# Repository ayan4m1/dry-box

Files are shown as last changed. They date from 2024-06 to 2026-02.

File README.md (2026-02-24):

# My Filament Dry Box Adventure

I'm not the first person to do this, but I wanted to document my specific method in case others find it useful.

I wanted a setup that could keep at least 20 spools of filament in a low-humidity (5-15%) environment.

The Sterilite 20 quart gasket box was chosen because it is popular for this purpose and fits my basic needs - it fits four 1kg spools of filament with minimal wasted space and the lid is gasketed to help keep moisture out.

I found a [spool holder design](https://www.printables.com/model/139303-sterilite-20-qt-gasket-box-spool-rack) on Printables by RCNet that uses 3/8" aluminum tubing, which can be bought in a coil and straightened, then cut to length and mounted between the endcaps to let four typical-size 1kg filament spools rest vertically in the box.

3A Molecular Sieve was chosen as the dessicant because it removes more water, faster than silica gel. It does take more heat/time to dry it back out than silica gel, but this should not be an issue if you have enough molecular sieve to rotate it.

I also wanted warnings/alarms for when the sieve granules needed changing, so the LOLIN D1 Mini was chosen as the microcontroller. They are cheap ($3.70 as of this writing), small, and fairly well designed.

**Energy Use Tangent:** The current draw of each ESP8266 in this application is estimated at 70mA based on [this research](https://www.ondrovo.com/a/20170207-esp-consumption/). That's 67mA continuously with "periodic spikes" which add up to an average of 3mA. This means that every six boxes consumes 420mA, or 50 Wh of energy a day (about $0.14/mo at my electricity prices) - assuming I make no optimizations whatsoever for the device to sleep in between polling periods. My television consumes ~260 Wh in standby mode every day. I could likely drop the average current for six sensors to 100mA with sleep optimizations. They would then consume 22 times less power than my television.

There is an SHT30 shield for the D1 mini, which provides our humidity sensing and is simple to socket onto the D1 mini. The SHT30 is a fairly accurate sensor (±2% RH) which will suffice for these purposes.

The firmware uses [ESP_WiFiManager_Lite](https://github.com/khoih-prog/ESP_WiFiManager_Lite) to simplify setup and configuration of the sensors. On first flashing, the sensor will go into Access Point mode with an SSID of `dry_box_1` and the password `drybox123`. Connect to it, then navigate to `http://192.168.4.1` in your browser. Set the WiFi credentials, device name, polling rate, humidity thresholds, and Discord webhook, then click Save. The device will reboot and start functioning. If you need to change configuration, "double-tap" the reset button on the microcontroller and wait a few seconds for a solid blue LED. This means that it is in Access Point mode again.

## Bill of Materials

### [LOLIN D1 Mini V4](https://www.aliexpress.us/item/3256806460241404.html)

The link above is the official LOLIN Aliexpress store. If it becomes unavailable, you can find clones of it by searching ["d1 mini v4"](https://www.amazon.com/ACEIRMC-Internet-ESP8266-Compatible-MicroPython/dp/B0CFY382JX) on Amazon.

### [LOLIN SHT30 Shield](https://www.aliexpress.us/item/2251832575822188.html)

The link above is the official LOLIN Aliexpress store. If this link becomes unavailable, you can use any [SHT30 Breakout Board](https://www.dfrobot.com/product-2012.html) and wire it to a [JST-SH1.0 4P connector](https://www.adafruit.com/product/4209). There is a receptacle labeled I2C on the bottom right of the D1 Mini v4 which accepts this connector.

### [USB-A to USB-C Cable](https://www.amazon.com/tekSonic-10-Pack-Type-C-Cables-Charge/dp/B0CG4GM7PM)

You need one of these for each dry box, to power the sensor inside. You will be chopping the USB-C ends off of these, in order to get the wire through the hole in the box.

The cables I got had fabric weave wrapping - this meant extra complexity because I had to trim the fraying ends and use CA glue to fix them in place 1-2 inches before the end of the USB cable. This gives enough room for stripping the wires later on.

### [USB-C Connector Breakout](https://www.amazon.com/ANMBEST-Connector-Receptacle-Adapter-Support/dp/B091CRLJM2)

In case the Amazon link above stops working, this is what you're looking for:

usb connector breakout close-up

### [M2 Threaded Inserts](https://www.amazon.com/AIEX-Printing-Embedment-Automotive-M2x3x3-5mm/dp/B0B8GN63S2)

These are for the sensor holders.

### [Sterilite 20 qt Boxes](https://www.amazon.com/Sterilite-19344304-Latched-Plastic-Container/dp/B002BA5F3O)

Amazon currently offers 6, 12, 18, and 24 packs. If this listing becomes unavailable, try [Target](https://www.target.com/p/sterilite-20-qt-gasket-box-stackable-storage-bin-with-latching-lid-and-tight-seal-plastic-container-to-organize-basement-clear-base-and-lid-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), [Walmart](https://www.walmart.com/ip/Sterilite-20-Quart-Clear-Plastic-Stacking-Storage-Container-with-Gasket-Lid-6-Pack/633637534), or [Home Depot](https://www.homedepot.com/p/Sterilite-20-Qt-Gasket-Box-with-Clear-Base-and-Lid-6-Pack-6-x-19324306/312922371).

### [3/8" Aluminum Tubing](https://www.amazon.com/Tubing-Aluminium-Refrigeration-Equipment-air-conditioning/dp/B0C43X6JR4)

This will be cut to 325 mm (12.75 inch) sections to act as the spool holders.

### [3A Molecular Sieve](https://www.amazon.com/Wisesorb-Molecular-Desiccant-Dehumidifier-Absorbers/dp/B085W6TXJ8)

The 2 pound size would provide for ~150 grams of sieve per box, in a six box setup.

graph showing molecular sieve taking about 15 minutes to dry to 15 percent RH

## Price Estimate

This is an estimate for a six box, 24-spool setup based on prices I paid in June 2024.

| Parts | Net Cost |
| --- | --- |
| D1 Mini | $23 |
| SHT30 Shield | $18 |
| USB Cable | $12 |
| Molecular Sieve  | $18 |
| 20 qt Boxes | $54 |
| USB Cables | $6 |
| USB-C Breakouts  | $5 |
| Threaded Inserts | $8 |
| Aluminum Tube | $25 |
| Total | $169 |

## Tools

- Drill
- CA glue
- Glue Gun
- Soldering Iron
- Wire Strippers (12-24 AWG)
- Belt Sander (or sandpaper and patience)
- [M2 Threaded Insert Tip for Soldering Iron](https://www.amazon.com/Virtjoule-Heat-Insert-Tips-Sizes/dp/B08B17VQLD)
- [3/8" Tubing Straightener](https://www.amazon.com/Watris-Veiyi-Straightener-Universal-Straightening/dp/B0BLYYPN91)
- [Metal Tubing Cutter](https://www.amazon.com/RIDGID-32975-Quarters-Tubing-Cutter/dp/B000LDGNCU)

## 3D Printed Parts

- Endcaps for aluminum tubing
- Dessicant tray
- Sensor mount

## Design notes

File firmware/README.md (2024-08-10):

# dry-box firmware

## parts

- [LOLIN D1 Mini](https://www.aliexpress.us/item/2251832342786284.html)
- [LOLIN SHT30 Shield for D1 Mini](https://www.aliexpress.us/item/2251832575822188.html)
- **todo:** add STL files for 3D print mount model

## usage

1. Open this directory in VS Code with PlatformIO installed.
2. Connect the target device via USB.
3. Use the `PlatformIO > Upload` action to flash the firmware.
4. Connect to the WiFi AP `Dry Box 1` with PSK `drybox123`.
5. Your browser should open and take you to the config page automatically. If not, go to `http://192.168.4.1`.
6. Set your WiFi settings, Discord Webhook URL, humidity thresholds, and polling rate. Click Save.
7. The device will now reboot and should be operational.

**NOTE:** Double-tap the reset button and wait a few seconds for a solid blue LED to get back into the config AP interface later on.

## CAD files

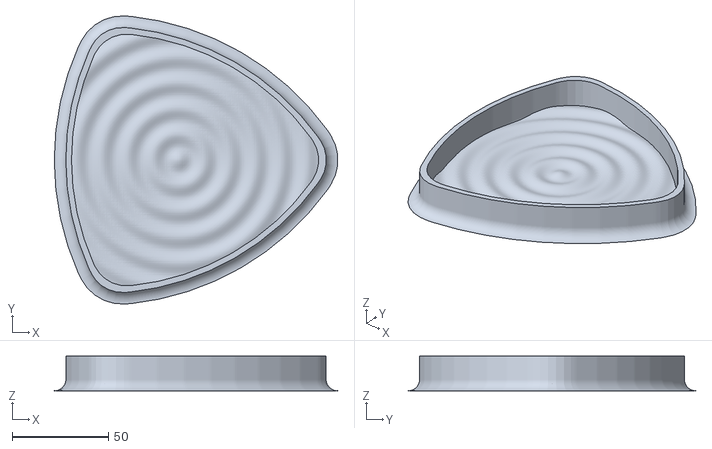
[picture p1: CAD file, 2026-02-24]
mechanical/dry-box-dessicant-tray.stl
147.0 x 149.4 x 18.0

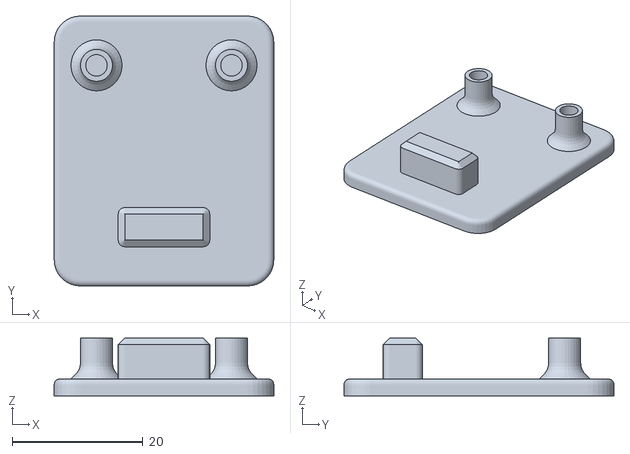
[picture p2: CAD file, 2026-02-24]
mechanical/dry-box-sensor-mount.stl
33.6 x 41.3 x 8.85

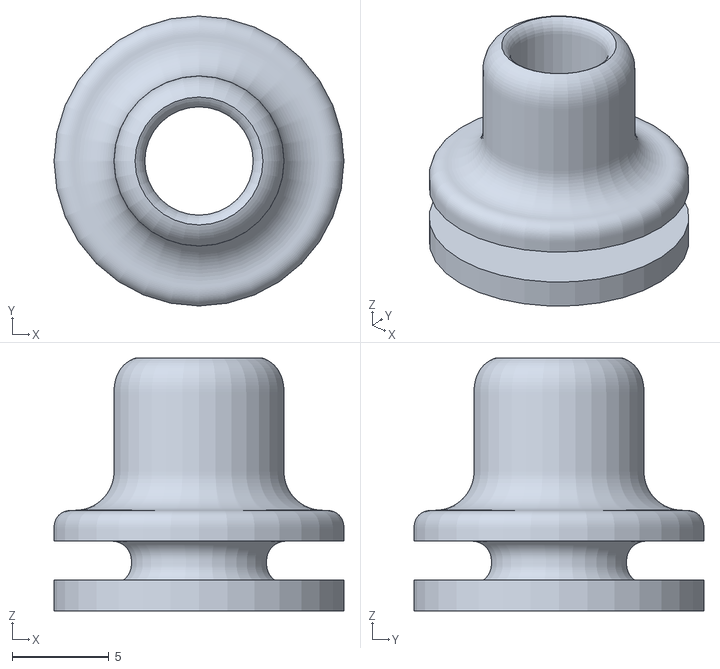
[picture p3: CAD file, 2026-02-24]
mechanical/dry-box-cable-gasket.stl
15.0 x 15.0 x 13.1

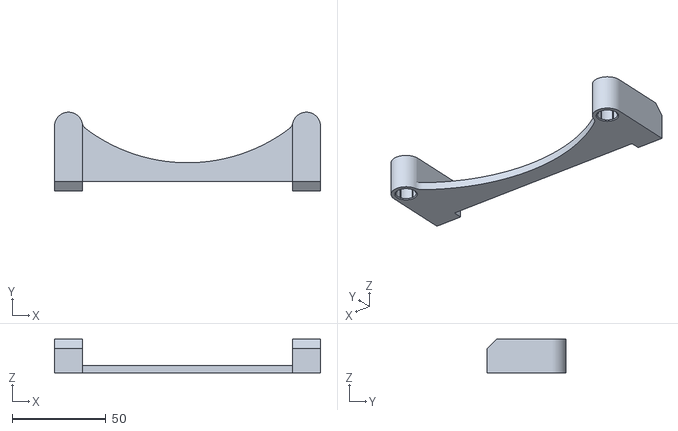
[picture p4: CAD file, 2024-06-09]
mechanical/spool-rack-endcap.stl
142.0 x 42.0 x 18.0

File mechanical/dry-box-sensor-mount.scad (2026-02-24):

include <BOSL2/std.scad>
include <BOSL2/rounding.scad>

$fn = 32;

d1_mini_dims = [25.6, 33.3, 1.6];

case_fillet = 2;
case_padding = 4;
case_rounding = 4;
case_height = 2.6;
case_inner_dims = [d1_mini_dims[0] + (case_padding * 2), d1_mini_dims[1] + (case_padding * 2)];

hole_diameter = 3 + 0.3;
hole_offset = 20.65;
hole_offsets = [[(d1_mini_dims[0] - hole_offset) / 2, 29.75], [(d1_mini_dims[0] + hole_offset) / 2, 29.75]];
insert_height = 3.5 * 1.5;

standoff_padding = 0.8;
standoff_height = insert_height + 1;
standoff_diameter = hole_diameter + (standoff_padding * 2);

prop_dims = [14, 6, standoff_height];
prop_offset = [0, -(d1_mini_dims[1] - 10) / 2, 0];

module case() {
union() {
translate([0, 0, case_height / 2]) offset_sweep(rect(case_inner_dims, rounding = case_rounding), top=os_smooth(joint = case_fillet / 2), height = case_height, steps=$fn);
translate([prop_offset[0], prop_offset[1], case_height + prop_dims[2] / 2]) offset_sweep(rect([prop_dims[0], prop_dims[1]], rounding = 1), top=os_chamfer(width = 1), height = prop_dims[2], steps = $fn);
}
}

module standoff() {
union() {
difference() {
    cylinder(d = standoff_diameter, h = standoff_height);
    translate([0, 0, standoff_height - insert_height]) cylinder(d = hole_diameter, h = insert_height);
}
rotate_extrude() translate([standoff_diameter / 2, 0, 0]) mask2d_teardrop(d = standoff_diameter);
}
}

/*%color("blue") render() translate([d1_mini_dims[0] / 2, -d1_mini_dims[1] / 2, 10]) rotate([180, 0, 180]) difference() {
    cube(d1_mini_dims);
    for(i = [0 : len(hole_offsets) - 1]) {
        hole_offset = hole_offsets[i];
        translate([hole_offset[0], hole_offset[1], 0]) cylinder(d = hole_diameter, h = d1_mini_dims[2]); 
    }
}*/

union() {
case();

translate([-d1_mini_dims[0] / 2, -d1_mini_dims[1] / 2, case_height]) {
    for(i = [0 : len(hole_offsets) - 1]) {
        hole_offset = hole_offsets[i];
        translate([hole_offset[0], hole_offset[1], 0]) standoff();
    }
}
}

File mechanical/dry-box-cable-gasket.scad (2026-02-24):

include <BOSL2/std.scad>
include <BOSL2/rounding.scad>

hole_diameter = 7;
cable_diameter = 5.6;
gasket_diameter_padding = 4;
gasket_diameter = hole_diameter + (gasket_diameter_padding * 2);
box_wall_thickness = 2;
gasket_wall_thickness = 1.6;
strain_relief_wall_thickness = 1.6;
strain_relief_height = 8;
strain_relief_diameter = cable_diameter + (strain_relief_wall_thickness * 2);

gasket_bottom_height = box_wall_thickness + (gasket_wall_thickness * 2);
gasket_height = gasket_bottom_height + strain_relief_height;

$fn = 32;

module ring(d_outer, d_inner, height) {
    difference() {
        cylinder(d = d_outer, h = height);
        translate([0, 0, (height / 2) - 0.1]) offset_sweep(circle(d = d_inner), height = height + 0.2, top = os_circle(r = -height / 2), bottom = os_circle(r = -height / 2));
    }
}

difference() {
union() {
translate([0, 0, gasket_bottom_height / 2]) offset_sweep(circle(d = gasket_diameter), height = gasket_bottom_height, top = os_smooth(joint = 1));
translate([0, 0, gasket_bottom_height + (strain_relief_height / 2)]) offset_sweep(circle(d = strain_relief_diameter), height = strain_relief_height, top = os_smooth(joint = 2), bottom = os_circle(r = -gasket_diameter_padding / 2));
}

translate([0, 0, gasket_height]) rounding_hole_mask(d = cable_diameter, rounding = 1);

translate([0, 0, (gasket_bottom_height - box_wall_thickness) / 2]) ring(gasket_diameter + 0.1, hole_diameter, box_wall_thickness);

translate([0, 0, -0.1]) cylinder(d = cable_diameter, h = gasket_height + 0.2);
}

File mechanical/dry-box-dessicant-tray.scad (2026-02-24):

include <BOSL2/std.scad>
include <BOSL2/rounding.scad>

$fn = 32;

tray_radius = 80;
tray_height = 18;
tray_rounding = 18;
tray_flare = -6;
tray_inner_fillet = 2;
tray_wall_thickness = 2;

anchor_points = [
    LEFT,
    TOP,
    DOWN,
    RIGHT+DOWN,
    LEFT+DOWN,
    LEFT+UP,
    RIGHT+UP,
    "tip0"
];

cutout_radius = 4;
cutout_thickness = tray_wall_thickness * 4;
cutout_magic_offset = [0, -4.5, 4];

module tray_shell(radius) {
    reuleaux_polygon(n = 3, r = radius);
}
function tray_shell(radius) =
    reuleaux_polygon(n = 3, r = radius);
function round_tray_shell(radius) =
    round_corners(tray_shell(radius), radius = tray_rounding);
module swept_round_tray_shell(radius = tray_radius, flare = undef) {
    offset_sweep(round_tray_shell(radius), height = tray_height, bottom = flare, steps=$fn);
}

ripple_height = 0.8;
ripple_density = 12;
ripple_function = function (x,y) ripple_height * cos(ripple_density * norm([x,y]));

module ripple() {
translate([0, 0, ripple_height]) intersection() {
    heightfield(size=[tray_radius * 2, tray_radius * 2], bottom=-2, data=ripple_function, xrange=[-180:2:180], yrange=[-180:2:180]);
    translate([0, 0, -tray_height / 2]) linear_extrude(tray_height) tray_shell(tray_radius - (tray_wall_thickness * 2) + tray_wall_thickness / 2);
}
}

difference() {
    swept_round_tray_shell(flare = os_circle(r = tray_flare));
    translate([0, 0, tray_wall_thickness]) swept_round_tray_shell(radius = tray_radius - tray_wall_thickness * 2, flare = os_smooth(joint = tray_inner_fillet));
    /*for(i = [0 : len(anchor_points) - 1]) {
        anchor_point = anchor_points[i];

        hide("hide") tag("hide") reuleaux_polygon(n = 3, r = tray_radius - tray_wall_thickness * 2) tag("keep") attach(anchor_point) translate(cutout_magic_offset) rotate([-90, 0, 0]) cylinder(r = cutout_radius, h = cutout_thickness);
    }*/
}

translate([0, 0, -6]) ripple();

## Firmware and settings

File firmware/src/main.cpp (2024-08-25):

#define USE_LITTLEFS true
#define DOUBLERESETDETECTOR_DEBUG false
#define USE_DYNAMIC_PARAMETERS true
#define USING_BOARD_NAME false
// set to 3 or 4 to enable info/debug logging respectively
#define _ESP_WM_LITE_LOGLEVEL_ 0
#define REQUIRE_ONE_SET_SSID_PW true
#define USING_MRD false

#include <Arduino.h>
#include <Discord_WebHook.h>
#include <ESP8266mDNS.h>
#include <ESP_WiFiManager_Lite.h>
#include <FastLED.h>
#include <WEMOS_SHT3X.h>

#define WIFI_PSK "drybox123"

#define DISCORD_WARNING_ICON "yellow_circle"
#define DISCORD_ALERT_ICON "red_circle"
#define DISCORD_ERROR_ICON "no_entry_sign"
#define DISCORD_CLEAR_ICON "green_circle"
#define DISCORD_PING_ICON "hourglass"
#define DISCORD_MSG_BUFFER 256

// start dynamic params
#define DEFAULT_DEVICE_NAME "Dry Box 1"
#define DEFAULT_POLLING_RATE "120"
#define DEFAULT_WEBHOOK_URL ""
#define DEFAULT_ALARM_THRESHOLD "30"
#define DEFAULT_WARNING_THRESHOLD "20"

#define MAX_PERCENTAGE_LEN 3
#define MAX_POLLING_RATE_LEN 5
#define MAX_DEVICE_NAME_LEN 32
#define MAX_DISCORD_WEBHOOK_LEN 192

bool LOAD_DEFAULT_CONFIG_DATA = false;
ESP_WM_LITE_Configuration defaultConfig;

char deviceName[MAX_DEVICE_NAME_LEN + 1] = DEFAULT_DEVICE_NAME;
char sensorPollingRate[MAX_POLLING_RATE_LEN + 1] = DEFAULT_POLLING_RATE;
char discordWebhookUrl[MAX_DISCORD_WEBHOOK_LEN + 1] = DEFAULT_WEBHOOK_URL;
char humidityAlarmThreshold[MAX_PERCENTAGE_LEN + 1] = DEFAULT_ALARM_THRESHOLD;
char humidityWarningThreshold[MAX_PERCENTAGE_LEN + 1] =
    DEFAULT_WARNING_THRESHOLD;

MenuItem myMenuItems[] = {
    {"snn", "Device Name", deviceName, MAX_DEVICE_NAME_LEN},
    {"hwt", "Warning %", humidityWarningThreshold, MAX_PERCENTAGE_LEN},
    {"hat", "Alarm %", humidityAlarmThreshold, MAX_PERCENTAGE_LEN},
    {"dwu", "Discord Webhook", discordWebhookUrl, MAX_DISCORD_WEBHOOK_LEN},
    {"spr", "Poll Rate (s)", sensorPollingRate, MAX_POLLING_RATE_LEN}};

uint16_t NUM_MENU_ITEMS = sizeof(myMenuItems) / sizeof(MenuItem);
// end dynamic params

SHT3X sensor;
uint16_t timesWarned = 0;
float lastHumidity = 0.0f;
bool alarmTripped = false;
Discord_Webhook* webhook = new Discord_Webhook();
ESP_WiFiManager_Lite* manager = new ESP_WiFiManager_Lite();

// start utility functions

bool areFloatsEqual(float a, float b, float epsilon = 0.01f) {
  return fabs(a - b) < epsilon;
}

float clampValue(float value, float epsilon = 1.0f) {
  return roundf(sensor.humidity * (1 / epsilon)) / (1 / epsilon);
}

String camelToSnake(const char* src) {
  String input = String(src);
  String result = "";

  char c = tolower(input[0]);
  result += char(c);

  for (uint16_t i = 1; i < input.length(); i++) {
    c = input[i];

    if (isupper(c)) {
      result += '_';
      result += char(tolower(c));
    } else if (isAlphaNumeric(c)) {
      result += c;
    }
  }

  return result;
}

void sendMessage(const char* message) {
  if (strlen(discordWebhookUrl) <= 0) {
    Serial.println(F("Invalid Discord webhook URL!"));
    return;
  }

  if (!webhook->send(message)) {
    Serial.println(F("Failed to trigger Discord webhook!"));
  }
}

void sendUpdateMessage(const char* icon) {
  const float humidity = sensor.humidity;
  char message[DISCORD_MSG_BUFFER];

  snprintf(message, DISCORD_MSG_BUFFER, ":%s: %s is at %.2f%% humidity", icon,
           deviceName, humidity);

  sendMessage(message);
}

void sendErrorMessage() {
  char message[DISCORD_MSG_BUFFER];

  snprintf(message, DISCORD_MSG_BUFFER, ":%s: %s has a sensor fault!",
           DISCORD_ERROR_ICON, deviceName);
  sendMessage(message);
}

bool pollSensor() {
  auto failed = sensor.get() != 0;

  if (failed) {
    Serial.println(F("Failed to poll sensor!"));
    sendErrorMessage();
    return false;
  }

  return true;
}

void checkSensorState() {
  uint8_t alarmThreshold = atoi(humidityAlarmThreshold);
  uint8_t warningThreshold = atoi(humidityWarningThreshold);

  if (alarmThreshold == 0 || warningThreshold == 0 ||
      warningThreshold > alarmThreshold) {
    Serial.println(F("Invalid thresholds, skipping update!"));
    return;
  }

  if (!pollSensor()) {
    return;
  }

  Serial.printf("Raw humidity is %.0f%%\n", sensor.humidity);

  auto lastValue = clampValue(lastHumidity);
  auto currentValue = clampValue(sensor.humidity);

  if (!areFloatsEqual(lastValue, currentValue)) {
    Serial.println(F("Humidity value has not changed significantly!"));
    return;
  }

  lastHumidity = currentValue;

  if (currentValue >= warningThreshold) {
    if (currentValue >= alarmThreshold) {
      alarmTripped = true;
      Serial.println(F("Alarm tripped"));
      sendUpdateMessage(DISCORD_ALERT_ICON);
    } else if (timesWarned < 10) {
      timesWarned++;
      sendUpdateMessage(DISCORD_WARNING_ICON);
    } else if (alarmTripped) {
      sendMessage(":zzz: Sleeping warnings for now");
      alarmTripped = false;
    }
  } else if (alarmTripped) {
    Serial.println(F("Alarm reset"));
    alarmTripped = false;
    timesWarned = 0;
    sendUpdateMessage(DISCORD_CLEAR_ICON);
  }
}

// end utility functions

void setup() {
  Serial.begin(115200);
  Serial.println();

  // load the dynamic data we need to get the device name
  manager->extLoadDynamicData();
  // Derive hostname from device name
  auto hostname = camelToSnake(deviceName);
  Serial.printf("Device name is %s\n", hostname.c_str());

  // Configure WiFi params if we are going into AP mode
  manager->setConfigPortal(hostname, WIFI_PSK);
  manager->begin(hostname.c_str());

  // Initialize the Discord webhook lib
  webhook->begin(discordWebhookUrl);

  Serial.println(F("Initialized"));

  // Post a startup message if we are set up
  if (!manager->isConfigMode()) {
    checkSensorState();
  }
}

void loop() {
  // Must be called once every loop()
  manager->run();

  // Get polling rate from dynamic params
  uint16_t pollingRate = atoi(sensorPollingRate);

  if (pollingRate == 0) {
    Serial.println(
        F("Warning: Polling rate is zero, no updates will be performed!"));
    return;
  } else if (manager->isConfigMode()) {
    return;
  }

  // Sensor polling loop
  EVERY_N_SECONDS(pollingRate) { checkSensorState(); }

  // Device healthcheck loop
  EVERY_N_HOURS(24) {
    if (pollSensor()) {
      sendUpdateMessage(DISCORD_PING_ICON);
    }
  }
}

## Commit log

2024-06-07 #pragma instead of #error
    [main.cpp]
2024-06-07 add multi-device flashing script
2024-06-07 switch to WiFiManager based setup
2024-06-07 allow resetting into config mode to change config
    [main.cpp]
2024-06-09 remove flash helper scripts and make everything, including device name, configurable at runtime
2024-06-09 add endcap STL
    [spool-rack-endcap.stl]
2024-08-09 add a daily "ping" to ensure sensors are running and add separate startup icon
2024-08-10 separate error/success message utility functions, add error logging
    [main.cpp]
2024-08-10 fix return if polling rate is zero
    [main.cpp]
2024-08-19 try to fix floating point comparisons, add comments
    [main.cpp]
2024-08-21 fix potential incorrect comparison
    [main.cpp]
2024-08-21 fix massive bug in compareValues implementation
    [main.cpp]
2024-08-23 hopefully fix comparison bug
    [main.cpp]
2024-08-23 add debug logging and rework float compare logic (thanks honeycrisis!)
    [main.cpp]
2024-08-23 clamp both values
2024-08-23 update lastHumidity if currentValue changes
2026-02-24 feat: add mechanical parts
    [dry-box-cable-gasket.scad, dry-box-cable-gasket.stl, dry-box-dessicant-tray.scad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]
